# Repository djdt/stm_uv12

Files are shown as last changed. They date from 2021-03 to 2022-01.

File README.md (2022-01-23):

# stm_uv12

This repository cotains the kicad files and code for a UVx irradiator designed to fit over a standard 12 well plate.
The controller is powered by a single protected 18650 Li-ion cell, each row of LEDs (3 rows of 4 LEDs) has a R1218x DC/DC converter for control of LED brightness.
Approximate doses (J/m^2) have been calculated using the expected LED outputs and are delivered at a specified rate using the controller.

## PCB Files

UVA_12W_LED_CONTROL: stm32 control board with 16x2 OLED screen (16pin connector).

UVA_12W_LED: board for use with 4x VLMU1610 UVA LEDs.

UVC_12W_LED: board for use with 4x SML-LXF3535UVC UVC LEDs.

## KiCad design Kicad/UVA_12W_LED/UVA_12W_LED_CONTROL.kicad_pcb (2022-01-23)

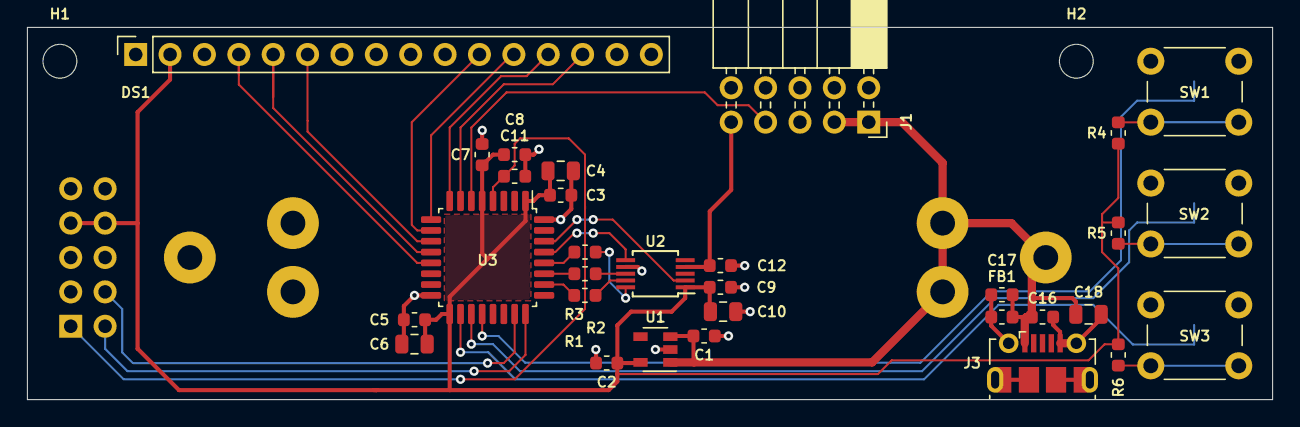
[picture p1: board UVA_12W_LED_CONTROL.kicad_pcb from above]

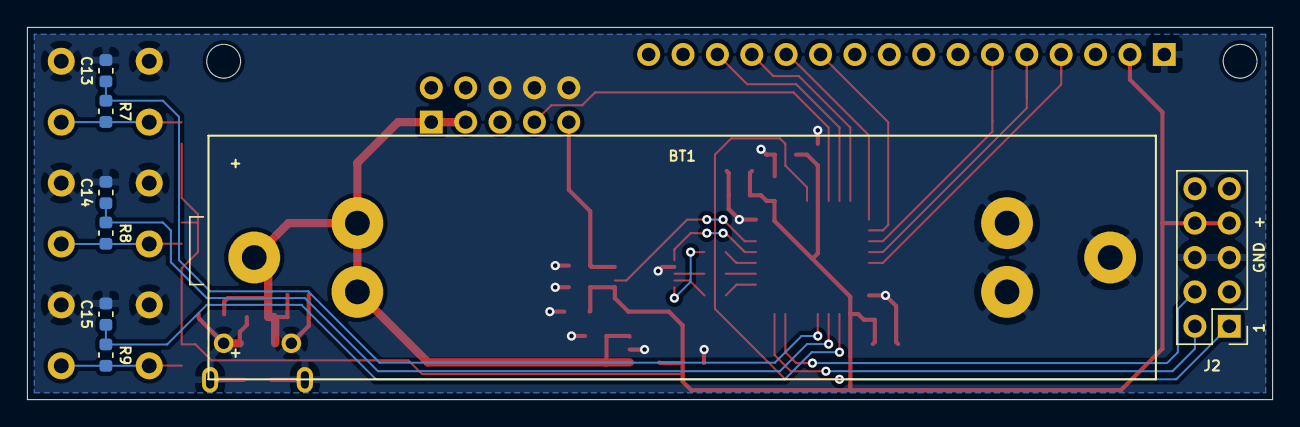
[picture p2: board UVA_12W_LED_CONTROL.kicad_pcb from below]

Board: 2 copper layers, 92.0 x 27.5 mm, 41 parts (8 on the bottom side), 29 nets.

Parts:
BT1: Battery; BatteryClip_18mm
C1, C2, C8: 1u; C_0603_1608Metric
C3, C5, C9, C11, C12, C17: 0u1; C_0603_1608Metric
C4, C6: 4u7; C_0805_2012Metric
C7, C13, C14, C15, C16: 10n; C_0603_1608Metric
C10, C18: 10u; C_0805_2012Metric
DS1: OLED-016N002A; PinSocket_1x16_P2.54mm_Vertical
FB1: Ferrite_Bead; L_0603_1608Metric
H1, H2: MountingHole; MountingHole_2.5mm
J1: Conn_02x05_Odd_Even; PinSocket_2x05_P2.54mm_Horizontal
J2: Conn_02x05_Odd_Even; PinHeader_2x05_P2.54mm_Vertical
J3: USB_B_Micro; USB_Micro-B_Molex-105017-0001
R1, R2, R3: 100; R_0603_1608Metric
R4, R5, R6, R7, R8, R9: 10k; R_0603_1608Metric
SW1, SW2, SW3: SW_Push; SW_PUSH_6mm
U1: MSCP1824T; SOT-23-5
U2: MCP48FVBX1; MSOP-10_3x3mm_P0.5mm
U3: STM32F042K6Tx; LQFP-32_7x7mm_P0.8mm

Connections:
/3V3: C2.1, C3.1, C4.1, C5.1, C6.1, C7.1, C8.1, C9.1, C10.1, DS1.2, J2.7, J2.8, R4.1, R5.1, R6.1, U1.5, U2.1, U3.1, U3.5, U3.17
/CS_DAC: U2.2, U3.30
/DB4: DS1.11, U3.10
/DB5: DS1.12, U3.9
/DB6: DS1.13, U3.8
/DB7: DS1.14, U3.7
/Dim: C12.1, J1.9, U2.4
/E: DS1.6, U3.11
/Enable: J1.7, U3.6
/MISO: R3.2, U2.8
/MOSI: R2.2, U3.28
/RS: DS1.4, U3.13
/RST: C11.1, J2.1, U3.4
/R~W: DS1.5, U3.12
/S1: C13.1, R7.1, U3.20
/S2: C14.1, R8.1, U3.19
/S3: C15.1, R9.1, U3.18
/SCLK: R1.2, U3.26
/SWCLK: J2.2, U3.24
/SWDIO: J2.4, U3.23
/Vbat: BT1.1, C1.1, C16.1, C17.1, C18.1, FB1.1, J1.1, J1.3, J3.1, U1.1, U1.3
/~LAT0: U2.6, U3.29
GND: BT1.2, C1.2, C2.2, C3.2, C4.2, C5.2, C6.2, C7.2, C8.2, C9.2, C10.2, C11.2, C12.2, C13.2, C14.2, C15.2, C16.2, C17.2, C18.2, DS1.1, FB1.2, J1.6, J1.8, J1.10, J2.5, J2.6, J3.5, J3.6, SW1.1, SW2.1, SW3.1, U1.2, U2.7, U3.16, U3.32
unnamed: R1.1, U2.9
unnamed: R2.1, U2.10
unnamed: R3.1, U3.27
unnamed: R4.2, R7.2, SW1.2
unnamed: R5.2, R8.2, SW2.2
unnamed: R6.2, R9.2, SW3.2

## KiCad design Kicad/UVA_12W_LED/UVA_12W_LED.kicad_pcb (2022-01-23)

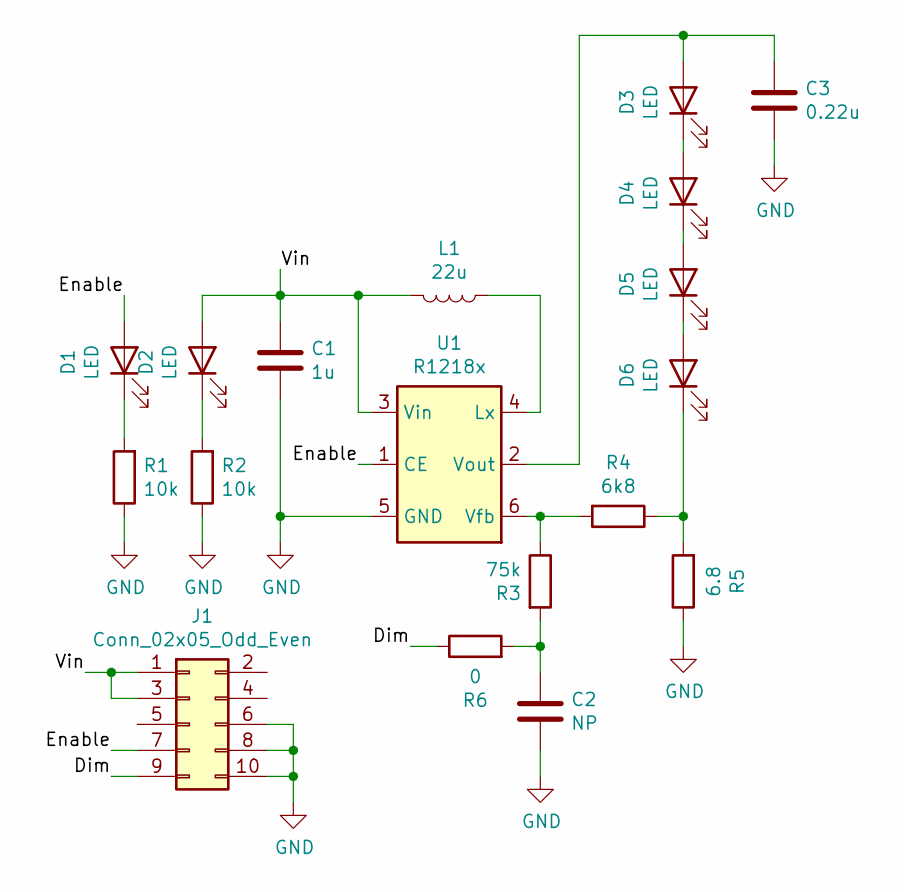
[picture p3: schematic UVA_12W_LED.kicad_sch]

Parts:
C1: 1u; C_0603_1608Metric
C2: NP; C_0603_1608Metric
C3: 0.22u; C_0603_1608Metric
D1, D2: LED; LED_0805_2012Metric
D3, D4, D5, D6: LED; VLMU1610
J1: Conn_02x05_Odd_Even; PinSocket_2x05_P2.54mm_Vertical_SMD
L1: 22u; L_0805_2012Metric
R1, R2: 10k; R_0603_1608Metric
R3: 75k; R_0603_1608Metric
R4: 6k8; R_0603_1608Metric
R5: 6.8; R_0603_1608Metric
R6: 0; R_0603_1608Metric
U1: R1218x; SOT-23-6

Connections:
/Dim: J1.9, R6.1
/Enable: D1.2 (A), J1.7, U1.1 (CE)
/Vin: C1.1, D2.2 (A), J1.1, J1.3, L1.2, U1.3 (Vin)
GND: C1.2, C2.2, C3.2, J1.6, J1.8, J1.10, R1.1, R2.1, R5.1, U1.5 (GND)
unnamed: C2.1, R3.2, R6.2
unnamed: C3.1, D3.2 (A), U1.2 (Vout)
unnamed: D1.1 (K), R1.2
unnamed: D2.1 (K), R2.2
unnamed: D3.1 (K), D4.2 (A)
unnamed: D4.1 (K), D5.2 (A)
unnamed: D5.1 (K), D6.2 (A)
unnamed: D6.1 (K), R4.1, R5.2
unnamed: L1.1, U1.4 (Lx)
unnamed: R3.1, R4.2, U1.6 (Vfb)

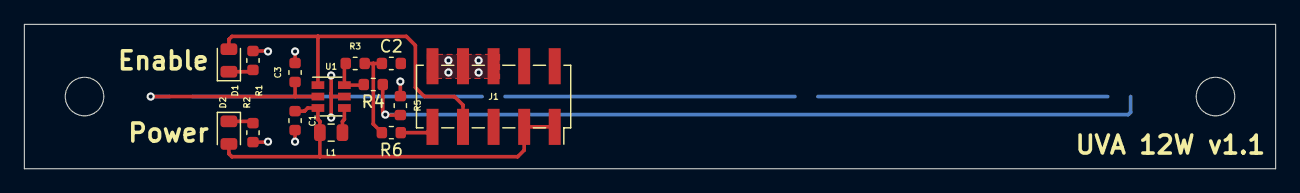
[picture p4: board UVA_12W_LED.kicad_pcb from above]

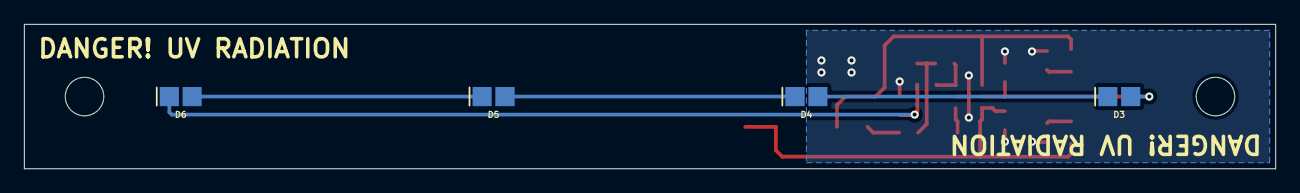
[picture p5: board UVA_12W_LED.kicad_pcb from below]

Board: 2 copper layers, 104.0 x 12.0 mm, 18 parts (4 on the bottom side), 14 nets.

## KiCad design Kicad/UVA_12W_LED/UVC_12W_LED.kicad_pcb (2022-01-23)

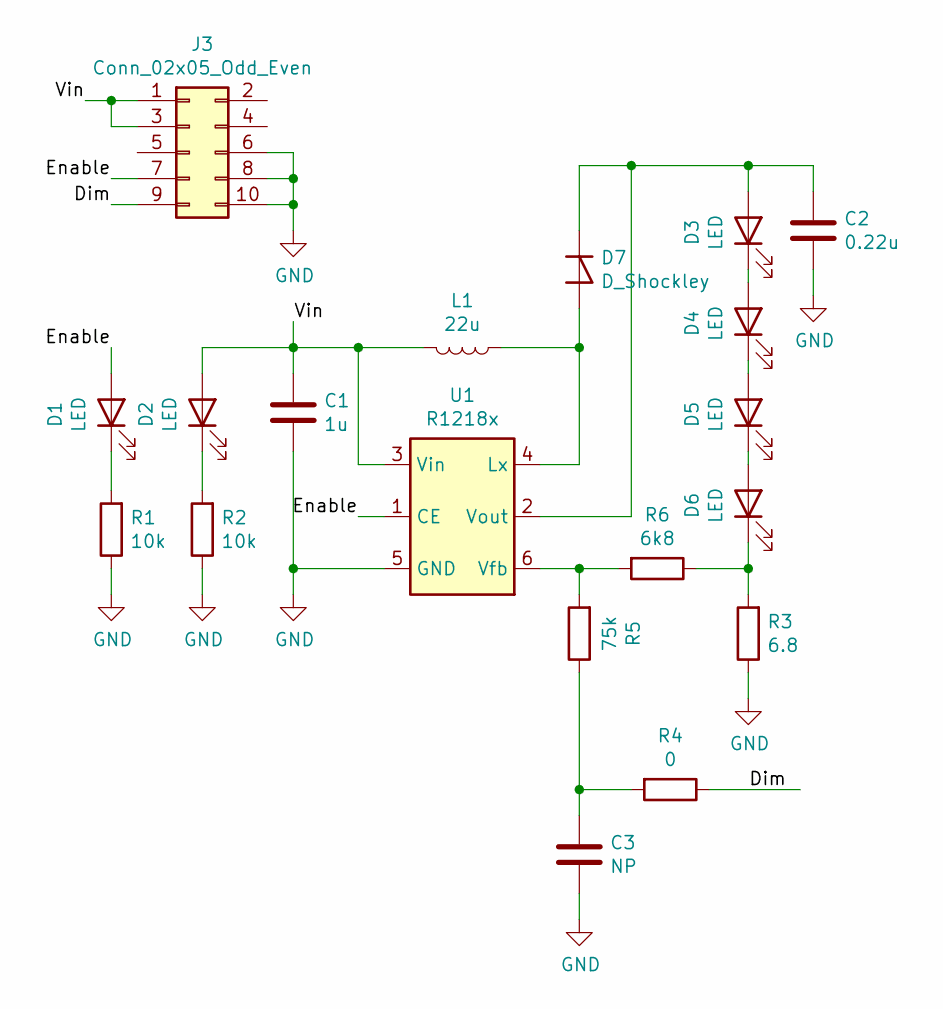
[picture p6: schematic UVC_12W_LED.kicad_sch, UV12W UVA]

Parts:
C1: 1u; C_0603_1608Metric
C2: 0.22u; C_0603_1608Metric
C3: NP; C_0603_1608Metric
D1, D2: LED; LED_0805_2012Metric
D3, D4, D5, D6: LED; SML-LXF3535UVC
D7: D_Shockley; D_SOD-123F
J3: Conn_02x05_Odd_Even; PinSocket_2x05_P2.54mm_Vertical_SMD
L1: 22u; L_Taiyo-Yuden_NR-30xx_HandSoldering
R1, R2: 10k; R_0603_1608Metric
R3: 6.8; R_0603_1608Metric
R4: 0; R_0603_1608Metric
R5: 75k; R_0603_1608Metric
R6: 6k8; R_0603_1608Metric
U1: R1218x; SOT-23-6

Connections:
/Dim: J3.9, R4.1
/Enable: D1.2 (A), J3.7, U1.1 (CE)
/Vin: C1.1, D2.2 (A), J3.1, J3.3, L1.2, U1.3 (Vin)
GND: C1.2, C2.2, C3.2, J3.6, J3.8, J3.10, R1.1, R2.1, R3.1, U1.5 (GND)
unnamed: C2.1, D3.2 (A), D7.1 (K), U1.2 (Vout)
unnamed: C3.1, R4.2, R5.1
unnamed: D1.1 (K), R1.2
unnamed: D2.1 (K), R2.2
unnamed: D3.1 (K), D4.2 (A)
unnamed: D4.1 (K), D5.2 (A)
unnamed: D5.1 (K), D6.2 (A)
unnamed: D6.1 (K), R3.2, R6.1
unnamed: D7.2 (A), L1.1, U1.4 (Lx)
unnamed: R5.2, R6.2, U1.6 (Vfb)

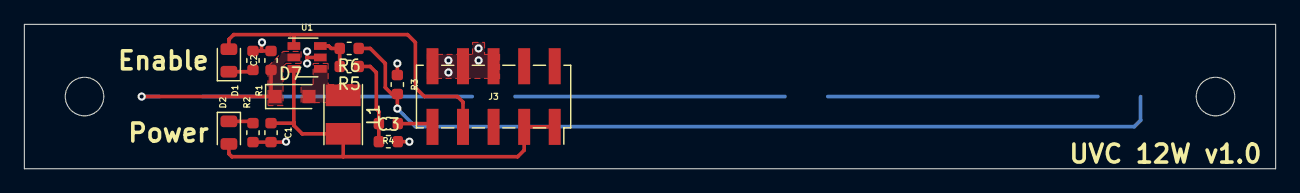
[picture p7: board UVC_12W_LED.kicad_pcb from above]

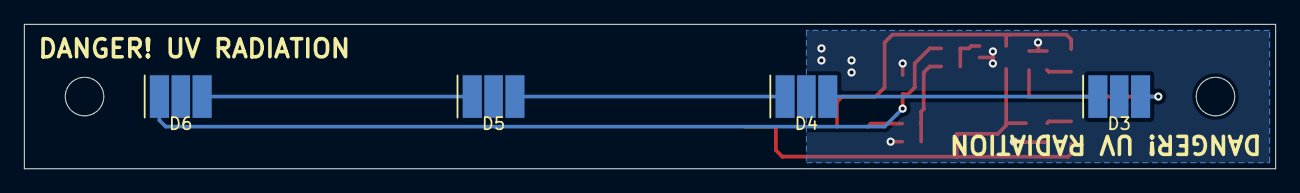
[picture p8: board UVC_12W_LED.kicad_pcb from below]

Board: 2 copper layers, 104.0 x 12.0 mm, 19 parts (4 on the bottom side), 14 nets.

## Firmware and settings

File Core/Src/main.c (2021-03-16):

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
/* Includes ------------------------------------------------------------------*/
#include "main.h"

/* USER CODE BEGIN Includes */
/* #include "animation.h" */
#include "mcp48fvb.h"
#include "oled0010.h"
/* USER CODE END Includes */

RTC_HandleTypeDef hrtc;

SPI_HandleTypeDef hspi1;

TIM_HandleTypeDef htim14;

/* USER CODE BEGIN PV */
mcp48fvb_t mcp = {
    &hspi1,
    CS_DAC_GPIO_Port, CS_DAC_Pin,
    LAT0_GPIO_Port, LAT0_Pin
};

uint16_t db_pins[8] = { 0, 0, 0, 0, DB4_Pin, DB5_Pin, DB6_Pin, DB7_Pin };
oled0010_t oled = {
    RS_GPIO_Port, RS_Pin,
    RW_GPIO_Port, RW_Pin,
    E_GPIO_Port, E_Pin,
    DB4_GPIO_Port, db_pins,
    0
};

state_t state = { STATE_SPLASH, UVMODE_A, UPDATE_NONE,
    0, DAC_MIN,
    0, 0, DOSE_STEP_SIZE, 0 };

char strbuf[16];
const char dose_units[] = "J/m"
                          "\x1e";
uint8_t len_dose_units = 4;
const char rate_units[] = "W/m"
                          "\x1e";
uint8_t len_rate_units = 4;

/* USER CODE END PV */

void SystemClock_Config(void);
static void MX_GPIO_Init(void);
static void MX_SPI1_Init(void);
static void MX_TIM14_Init(void);
static void MX_RTC_Init(void);
/* USER CODE BEGIN 0 */

void get_time_string(char* str, RTC_TimeTypeDef* t)
{
    str[0] = (t->Minutes >> 4) + '0';
    str[1] = (t->Minutes & 0x0f) + '0';
    str[2] = ':';
    str[3] = (t->Seconds >> 4) + '0';
    str[4] = (t->Seconds & 0x0f) + '0';
}

uint8_t get_seconds_string(char* str, uint16_t seconds)
{
    uint8_t h = seconds / 3600;
    uint8_t m = (seconds / 60) % 60;
    uint8_t s = seconds % 60;

    uint8_t i = 0;
    str[i++] = h / 10 + '0';
    str[i++] = h % 10 + '0';
    str[i++] = ':';
    str[i++] = m / 10 + '0';
    str[i++] = m % 10 + '0';
    str[i++] = ':';
    str[i++] = s / 10 + '0';
    str[i++] = s % 10 + '0';
    str[i] = '\0';
    return i;
}

uint8_t get_int_string(char* str, uint32_t n)
{
    uint8_t i = 0;

    // Get string last digit first
    do {
        str[i++] = n % 10 + '0';
    } while (((n /= 10) > 0));

    uint8_t l = i;
    i -= 1;

    // Reverse the string
    char t;
    for (uint8_t j = 0; j < i; ++j, --i) {
        t = str[j];
        str[j] = str[i];
        str[i] = t;
    }
    str[l] = '\0';

    return l;
}

uint8_t get_decimal_string(char* str, uint32_t n, uint8_t decimals)
{
    uint16_t d = 1;
    for (uint8_t i = 0; i < decimals; ++i) {
        d *= 10;
    }

    uint8_t l = get_int_string(str, n / d);
    str[l++] = '.';

    uint8_t l2 = get_int_string(str + l, n % d);
    for (uint8_t i = 0; i < decimals - l2; ++i) {
        for (uint8_t j = l + decimals; j > l; --j) {
            str[j] = str[j - 1];
        }
        str[l + i] = '0';
    }
    // Terminate overlong strings
    str[l + decimals] = '\0';

    return l + decimals;
}

void oled_pad(oled0010_t* oled, uint8_t n)
{
    while (n-- > 0) {
        oled_print_char(oled, ' ');
    }
}

void print_splash(oled0010_t* oled)
{
    oled_move_cursor(oled, 0, 0);
    oled_print(oled, "\x1d"
                     "Cell Destroyer"
                     "\x1d");
    oled_move_cursor(oled, 10, 1);
    oled_print(oled, "v0.2.2");
}

void print_uv_select(oled0010_t* oled, enum UVMODE mode)
{
    oled_move_cursor(oled, 0, 0);
    oled_print(oled, "Select Module");
    oled_move_cursor(oled, 15, 0);
    oled_print_char(oled, '\xc5');

    oled_move_cursor(oled, 0, 1);
    oled_print(oled, mode == UVMODE_A ? "UVA" : (mode == UVMODE_B ? "UVB" : "UVC"));
    oled_print(oled, " Module");
    oled_move_cursor(oled, 15, 1);
    oled_print_char(oled, '\xc6');
}

void print_dose_select(oled0010_t* oled, uint32_t dose)
{
    uint8_t len = get_int_string(strbuf, dose / 1000);

    oled_move_cursor(oled, 0, 0);
    oled_print(oled, "Total Dose");
    oled_move_cursor(oled, 15, 0);
    oled_print_char(oled, '\xc5');

    oled_move_cursor(oled, 0, 1);
    oled_pad(oled, 15 - len - (len_dose_units + 1));
    oled_print(oled, strbuf);
    oled_print_char(oled, ' ');
    oled_print(oled, (char*)dose_units);

    oled_move_cursor(oled, 15, 1);
    oled_print_char(oled, '\xc6');
}

void print_rate_select(oled0010_t* oled, uint32_t rate)
{
    uint32_t len = get_decimal_string(strbuf, rate, 3);

    oled_move_cursor(oled, 0, 0);
    oled_print(oled, "Dose Rate");
    oled_move_cursor(oled, 15, 0);
    oled_print_char(oled, '\xc5');

    oled_move_cursor(oled, 0, 1);
    oled_pad(oled, 15 - len - (len_dose_units + 1));
    oled_print(oled, strbuf);
    oled_print_char(oled, ' ');
    oled_print(oled, (char*)rate_units);

    oled_move_cursor(oled, 15, 1);
    oled_print_char(oled, '\xc6');
}

void print_main(oled0010_t* oled, char sym, enum UVMODE mode, uint32_t seconds, uint32_t delivered)
{
    uint8_t len = get_seconds_string(strbuf, seconds);
    oled_move_cursor(oled, 0, 0);
    oled_print(oled, mode == UVMODE_A ? "UVA" : (mode == UVMODE_B ? "UVB" : "UVC"));
    oled_move_cursor(oled, 4, 0);
    oled_print_char(oled, sym);
    oled_move_cursor(oled, 16 - len, 0);
    oled_print(oled, strbuf);

    len = get_decimal_string(strbuf, delivered, 3);
    oled_move_cursor(oled, 0, 1);
    oled_pad(oled, 15 - len - len_dose_units);
    oled_print(oled, strbuf);
    oled_print_char(oled, ' ');
    oled_print(oled, (char*)dose_units);
}

/* USER CODE END 0 */

/**
  * @brief  The application entry point.
  * @retval int
  */
int main(void)
{
    /* MCU Configuration--------------------------------------------------------*/

    /* Reset of all peripherals, Initializes the Flash interface and the Systick. */
    HAL_Init();

    /* Configure the system clock */
    SystemClock_Config();

    /* Initialize all configured peripherals */
    MX_GPIO_Init();
    MX_SPI1_Init();
    MX_TIM14_Init();
    MX_RTC_Init();
    /* USER CODE BEGIN 2 */
    // Disable interrupts
    HAL_NVIC_DisableIRQ(RTC_IRQn);
    HAL_NVIC_DisableIRQ(EXTI4_15_IRQn);

    // Ensure that the UV is not enabled
    HAL_GPIO_WritePin(Enable_GPIO_Port, Enable_Pin, GPIO_PIN_RESET);

    // Init the DAC
    HAL_Delay(50);
    mcp_init(&mcp, MCP_VREF_GAP, MCP_PWRD_NORM, MCP_GAIN_1X);
    mcp_set_dac(&mcp, DAC_MAX);

    // Start the display
    oled_init(&oled,
        OLED_FS_4BIT | OLED_FS_2LINES | OLED_FS_FONT_SMALL | OLED_FS_FONT_WEST_EUR2,
        OLED_DC_BLINK_OFF | OLED_DC_CURSOR_OFF,
        OLED_EM_INC | OLED_EM_DISP_SHIFT_OFF);

    // Print welcome message
    print_splash(&oled);

    // Reenable the button interrupts
    HAL_NVIC_EnableIRQ(RTC_IRQn);
    HAL_NVIC_EnableIRQ(EXTI4_15_IRQn);
    /* USER CODE END 2 */

    /* Infinite loop */
    /* USER CODE BEGIN WHILE */
    while (1) {
        /* HAL_NVIC_DisableIRQ(RTC_IRQn); */
        if (state.update & UPDATE_DISPLAY) {
            oled_clear_display(&oled);
            state.update &= ~UPDATE_DISPLAY;
        }
        if (state.update & UPDATE_DAC) {
            mcp_set_dac(&mcp, state.dac);
            state.update &= ~UPDATE_DAC;
        }
        if (state.update & UPDATE_ENABLE) {
            HAL_GPIO_WritePin(Enable_GPIO_Port, Enable_Pin,
                state.enabled ? GPIO_PIN_SET : GPIO_PIN_RESET);
            state.update &= ~UPDATE_ENABLE;
        }

        switch (state.display) {
        case STATE_UV_SELECT:
            print_uv_select(&oled, state.mode);
            break;
        case STATE_DOSE_SELECT:
            print_dose_select(&oled, state.dose);
            break;
        case STATE_RATE_SELECT:
            print_rate_select(&oled, state.rate);
            break;
        case STATE_PAUSED:
            print_main(&oled, '=', state.mode, state.remaining, state.delivered);
            break;
        case STATE_RUNNING:
            print_main(&oled, '\xf6', state.mode, state.remaining, state.delivered);
            break;
        case STATE_FINISHED:
            print_main(&oled, '\xfe', state.mode, state.remaining, state.delivered);
            break;
        default:
            break;
        }

        /* USER CODE END WHILE */

        /* USER CODE BEGIN 3 */
        /* HAL_NVIC_EnableIRQ(RTC_IRQn); */
        HAL_SuspendTick();
        HAL_PWR_EnterSLEEPMode(PWR_LOWPOWERREGULATOR_ON, PWR_SLEEPENTRY_WFE);
        HAL_ResumeTick();
    }
    /* USER CODE END 3 */
}

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


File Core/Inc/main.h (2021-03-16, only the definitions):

#define Enable_Pin GPIO_PIN_0
#define Enable_GPIO_Port GPIOA
#define DB7_Pin GPIO_PIN_1
#define DB7_GPIO_Port GPIOA
#define DB6_Pin GPIO_PIN_2
#define DB6_GPIO_Port GPIOA
#define DB5_Pin GPIO_PIN_3
#define DB5_GPIO_Port GPIOA
#define DB4_Pin GPIO_PIN_4
#define DB4_GPIO_Port GPIOA
#define E_Pin GPIO_PIN_5
#define E_GPIO_Port GPIOA
#define RW_Pin GPIO_PIN_6
#define RW_GPIO_Port GPIOA
#define RS_Pin GPIO_PIN_7
#define RS_GPIO_Port GPIOA
#define S1_Pin GPIO_PIN_8
#define S1_GPIO_Port GPIOA
#define S1_EXTI_IRQn EXTI4_15_IRQn
#define S2_Pin GPIO_PIN_9
#define S2_GPIO_Port GPIOA
#define S2_EXTI_IRQn EXTI4_15_IRQn
#define S3_Pin GPIO_PIN_10
#define S3_GPIO_Port GPIOA
#define S3_EXTI_IRQn EXTI4_15_IRQn
#define LAT0_Pin GPIO_PIN_6
#define LAT0_GPIO_Port GPIOB
#define CS_DAC_Pin GPIO_PIN_7
#define CS_DAC_GPIO_Port GPIOB
#define DOSE_MAX 10 * 1000 * 1000
#define DOSE_STEP_SIZE 100 * 1000
#define DAC_MIN 16 // 30.0 mA
#define DAC_MAX 252 // 0.0 mA
#define DAC_STEPS (DAC_MAX - DAC_MIN)
#define DAC_STEP_SIZE 1
#define UVA_RATE_MAX 11763 // mJ/m2/s
#define UVB_RATE_MAX 0 // mJ/m2/s
#define UVC_RATE_MAX 921 // mJ/m2/s
#define UVA_RATE_STEP (UVA_RATE_MAX / DAC_STEPS)
#define UVB_RATE_STEP (UVB_RATE_MAX / DAC_STEPS)
#define UVC_RATE_STEP (UVC_RATE_MAX / DAC_STEPS)

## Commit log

2020-10-13 return val, fix cs and lat
    [mcp48fvb.c]
2020-10-22 add buttons
2020-10-22 fix buttons
2020-10-22 added timer based repeat on hold
2020-10-24 printing of EFD
2020-10-24 use a mask for updates, redid display printing
2020-10-24 speed up buttons, efd prints correctly
    [main.c, main.h]
2020-11-02 add printing funcs
2020-11-04 add animation frames
2020-12-08 dose units everywhere, new time prints hours too
2022-01-23 added kicad files for PCBs
    [UVA_12W_LED.kicad_pcb, UVA_12W_LED.kicad_sch, UVA_12W_LED_CONTROL.kicad_pcb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]

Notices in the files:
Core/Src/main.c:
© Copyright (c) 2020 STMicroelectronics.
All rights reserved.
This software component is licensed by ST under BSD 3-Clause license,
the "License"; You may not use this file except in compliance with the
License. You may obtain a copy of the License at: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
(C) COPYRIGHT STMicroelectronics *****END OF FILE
